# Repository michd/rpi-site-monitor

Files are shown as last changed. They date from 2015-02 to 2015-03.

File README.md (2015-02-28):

# Raspberry Pi Site monitor

A dual colour LED-based website monitor for the Raspberry Pi. 

Using red+green 3-pin LEDs, you can create 3 colours: red, green, and yellow. These work well for status indication, so they are a good choice for a website monitor.

There's a bit of python in here that deals with the Raspberry PI's General Purpose In/Out (GPIO) pins, which drives the LEDs. The rest is dealt with through a Bash script.

The bash script first pings a hostname (such as example.com). If it doesn't respond to ping, it will turn the LED to red. If it does respond to ping, it will use curl to determine the HTTP status of a given page on the website. If this status is 200 or 204, it will turn the LED to green. If the HTTP status is anything else, yellow.

If you're better at reading pseudo code instead of text:

```
if (site responds to ping):
  if (page http status is 200 or 204):
    LED color = green
  else:
    LED color = yellow
else:
  LED color = red
```

## Requirements

- Hardware:
  - A Raspberry pi set up with networking
  - Some red+green dual color LEDs (or just a red and green LED per site)
  - NPN transistors to drive the LEDs (BC547-B will do fine)
  - Some resistors (I used 2x 1k Ohm + 2x 220 Ohm per dual colour LED)
  
  Refer to the eagle folder for a schematic and a PCB design with 5 LEDs set up.
- Software:
  - Python
  - Python RPi.GPIO
  - Curl

## Usage

Clone or download the repository, wire up the electronics. In a terminal on your RPi, go to the directory with this code, and run:

```
sudo ./monitor
```

If that doesn't work (probably if you've downloaded this a zip), make `monitor` executable:

```
chmod +x monitor
```

and try running it again. It won't produce any output, and will keep running until you hit Ctrl-C.

### Customise your configuration

By defauly, site monitor uses, you guessed it, default.conf for the configuration. This file contains documented settings and three example websites to status check. To use it for your own sites, make a copy of `default.conf`, and edit it with your favorite text editor. Then, run monitor, specifying your new config as an argument:

```
sudo ./monitor my-config.conf
```

### Console output
To see the status is of the things you're testing, run it with `-v` or `-vv` for more detail:

```
sudo ./monitor -v
```

## To do

See [Issues](https://github.com/michd/rpi-site-monitor/issues) on GitHub.

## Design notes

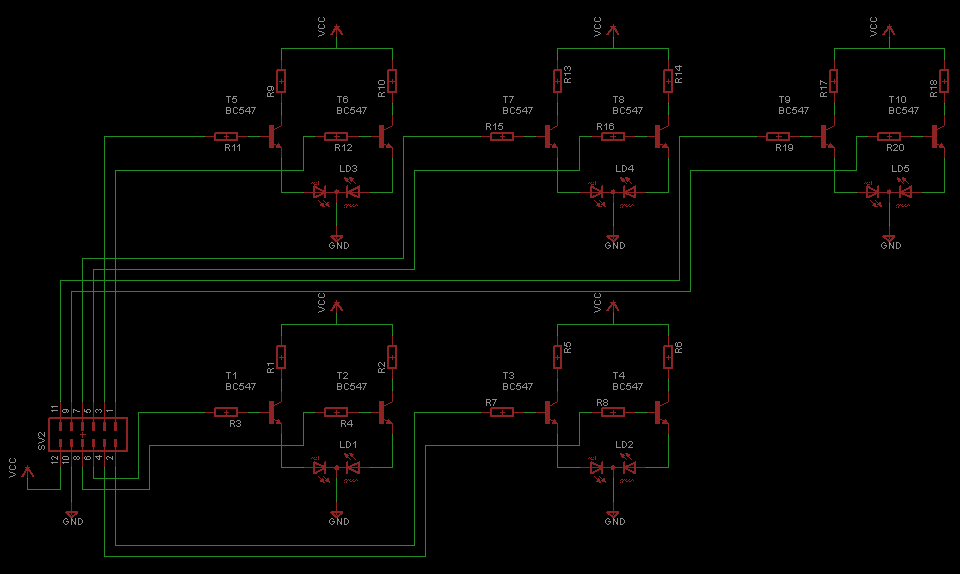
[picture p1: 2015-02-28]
eagle/5-leds-schematic.PNG

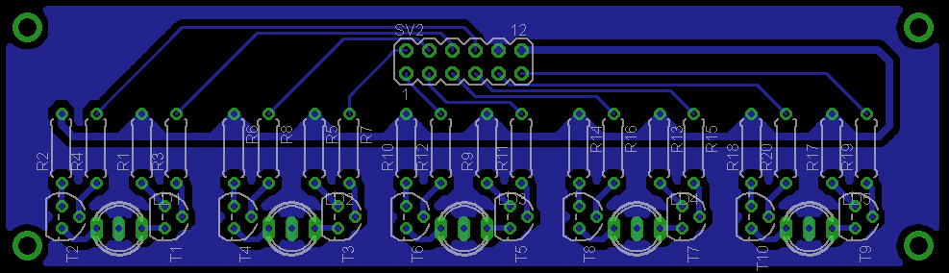
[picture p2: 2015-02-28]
eagle/5-leds-board.png

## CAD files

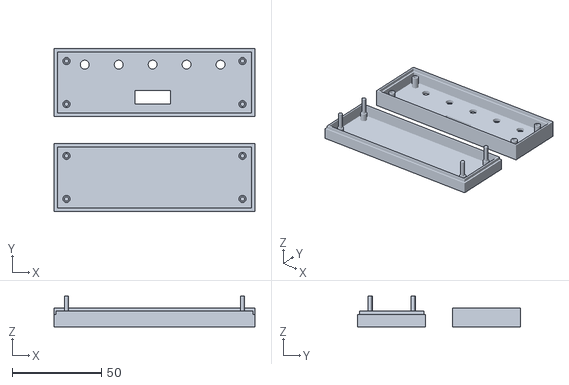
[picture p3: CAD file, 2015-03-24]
openscad/box.stl
112.5 x 91.2 x 17.3

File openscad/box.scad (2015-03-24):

// This design is parameterized based on holes in a PCB.
// It assumes that the PCB has 4 holes, evenly spaced as
// corners of a rectangle.

// Note: width refers to X axis, depth to Y, height to Z

// Edit these parameters for your own board dimensions

ceiling_distance_to_board = 7;

wall_thickness = 2;
floor_thickness = 2;
ceiling_thickness = 2;


hole_spacing_x = 98.5;
hole_spacing_y = 24.1;

hole_diameter = 2.5;
standoff_diameter = 4;

// How much the PCB needs to be raised from the bottom
// to leave room for solderings and whatnot
standoff_height = 5;
board_thickness = 1.65;


bottom_wall_height = standoff_height;
top_wall_height = ceiling_distance_to_board + board_thickness;
// Total height of box = floor_thickness + ceiling_thickness + bottom_wall_height + top_wall_height

// padding between standoff and wall
padding_left = 3;
padding_right = 3;
padding_back = 3;
padding_front = 3;

// ridge where bottom and top off box can overlap
// Make sure this isn't less than top_wall_height
ridge_height = 2;

// Project-specific params
led_diameter = 5;
first_led_offset_x = 10.2;
first_led_offset_y = 2;
led_origin_spacing = 19;
num_leds = 5;

connector_origin_x = 48.3;
connector_origin_y = 20.3;
connector_width = 20;
connector_depth = 7.5;

//-------------------------------------------------------------------

// Calculated globals
pin_height = bottom_wall_height + top_wall_height - standoff_height; 


module ceilingless_box(width, depth, height) {
    // Floor
    cube([width, depth, floor_thickness]);
    
    // Left wall
    translate([0, 0, floor_thickness])
        cube([
            wall_thickness,
            depth,
            height]);
    
    // Right wall
    translate([width - wall_thickness, 0, floor_thickness])
        cube([
            wall_thickness,
            depth,
            height]);
    
    // Rear wall
    translate([wall_thickness, depth - wall_thickness, floor_thickness])
        cube([
            width - 2 * wall_thickness,
            wall_thickness,
            height]);
    
    // Front wall
    translate([wall_thickness, 0, floor_thickness])
        cube([
            width - 2 * wall_thickness,
            wall_thickness,
            height]);
}

module bottom_case() {
    floor_width = hole_spacing_x + standoff_diameter + padding_left + padding_right + wall_thickness * 2;
    floor_depth = hole_spacing_y + standoff_diameter + padding_front + padding_back + wall_thickness * 2;
    
    module box() {
        ceilingless_box(floor_width, floor_depth, bottom_wall_height);        
        
        // Left Ridge
        translate([
            wall_thickness / 2,
            wall_thickness / 2,
            floor_thickness + bottom_wall_height])
            cube([
                wall_thickness / 2,
                floor_depth - wall_thickness,
                ridge_height]);
        
        
        // Right Ridge
        translate([
            floor_width - wall_thickness,
            wall_thickness / 2,
            floor_thickness + bottom_wall_height])
            cube([
                wall_thickness / 2,
                floor_depth - wall_thickness,
                ridge_height]);
                
        // Rear Ridge
        translate([
            wall_thickness,
            floor_depth - wall_thickness,
            floor_thickness + bottom_wall_height])
            cube([
                floor_width - wall_thickness * 2,
                wall_thickness / 2,
                ridge_height]);
                
        // Front Ridge
        translate([
            wall_thickness,
            wall_thickness / 2,
            floor_thickness + bottom_wall_height])
            cube([
                floor_width - 2 * wall_thickness,
                wall_thickness / 2,
                ridge_height
            ]);
    }
        
    
    // Place the standoffs and through-PCB pins in the box
    module pcb_holder() {        
        base_offset_x = wall_thickness + padding_left + standoff_diameter / 2;
        base_offset_y = wall_thickness + padding_front + standoff_diameter / 2;
        
        module pin() {
            // Standoff
            translate([0, 0,  standoff_height / 2])
                cylinder(
                    r = standoff_diameter / 2,
                    h = standoff_height,
                    center = true,
                    $fn = 20);
            
            // Through-PCB ping
            translate([0, 0, standoff_height + (board_thickness + pin_height) / 2])
                cylinder(
                    r = hole_diameter / 2,
                    h = board_thickness + pin_height,
                    center = true,
                    $fn = 20);
        }
        
        // Front left
        translate([base_offset_x, base_offset_y, floor_thickness])
            pin();
        
        // Front right
        translate([base_offset_x + hole_spacing_x, base_offset_y, floor_thickness])
            pin();
        
        // Rear left
        translate([base_offset_x, base_offset_y + hole_spacing_y, floor_thickness])
            pin();
        
        // Rear right
        translate([base_offset_x + hole_spacing_x, base_offset_y + hole_spacing_y, floor_thickness])
            pin();
        
    }
    
    box();
    pcb_holder();
}
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

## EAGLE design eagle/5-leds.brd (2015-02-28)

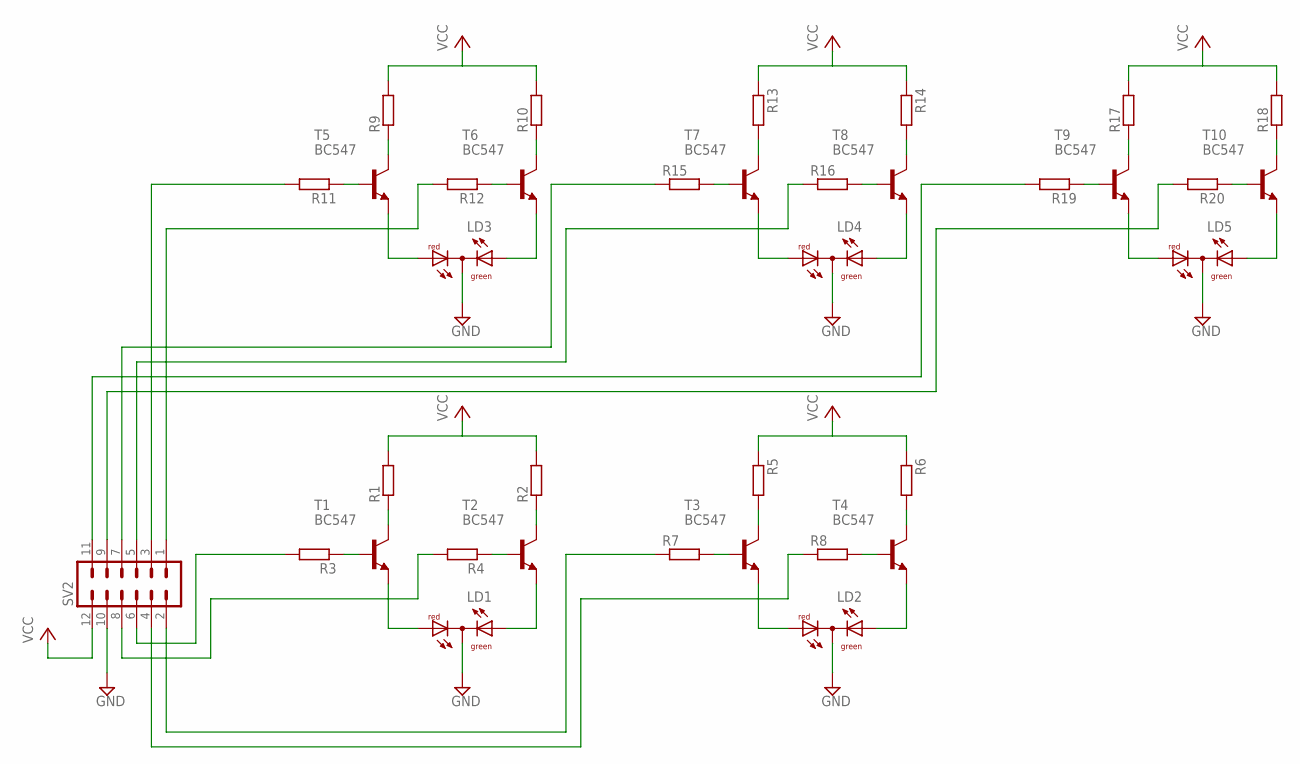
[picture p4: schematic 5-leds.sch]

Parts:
LD1, LD2, LD3, LD4, LD5: DUOLED-RG-C; DUOLED-C-5MM
R1, R2, R3, R4, R5, R6, R7, R8, R9, R10, R11, R12, R13, R14, R15, R16, R17, R18, R19, R20: R-EU_0207/7; 0207/7
SV2: MA06-2
T1, T2, T3, T4, T5, T6, T7, T8, T9, T10: BC547; TO92

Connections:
GND: LD1.C, LD2.C, LD3.C, LD4.C, LD5.C, SV2.10
unnamed: LD1.AR, T1.1 (E)
unnamed: LD1.AX (AG), T2.1 (E)
unnamed: R3.1, T1.2 (B)
unnamed: R4.1, T2.2 (B)
unnamed: R4.2, SV2.8
unnamed: R3.2, SV2.6
unnamed: R1.1, T1.3 (C)
unnamed: R2.1, T2.3 (C)
unnamed: LD2.AR, T3.1 (E)
unnamed: LD2.AX (AG), T4.1 (E)
unnamed: R8.1, SV2.4
unnamed: R5.2, T3.3 (C)
unnamed: R6.2, T4.3 (C)
unnamed: R7.2, T3.2 (B)
unnamed: R8.2, T4.2 (B)
unnamed: R7.1, SV2.2
unnamed: LD3.AR, T5.1 (E)
unnamed: LD3.AX (AG), T6.1 (E)
unnamed: R12.2, SV2.1
unnamed: R9.1, T5.3 (C)
unnamed: R10.1, T6.3 (C)
unnamed: R11.1, T5.2 (B)
unnamed: R12.1, T6.2 (B)
unnamed: R11.2, SV2.3
unnamed: LD4.AR, T7.1 (E)
unnamed: LD4.AX (AG), T8.1 (E)
unnamed: R16.1, SV2.5
unnamed: R13.2, T7.3 (C)
unnamed: R14.2, T8.3 (C)
unnamed: R15.2, T7.2 (B)
unnamed: R16.2, T8.2 (B)
unnamed: R15.1, SV2.7
unnamed: LD5.AR, T9.1 (E)
unnamed: LD5.AX (AG), T10.1 (E)
unnamed: R20.2, SV2.9
unnamed: R17.1, T9.3 (C)
unnamed: R18.1, T10.3 (C)
unnamed: R19.1, T9.2 (B)
unnamed: R20.1, T10.2 (B)
unnamed: R19.2, SV2.11
VCC: R1.2, R2.2, R5.1, R6.1, R9.2, R10.2, R13.1, R14.1, R17.2, R18.2, SV2.12

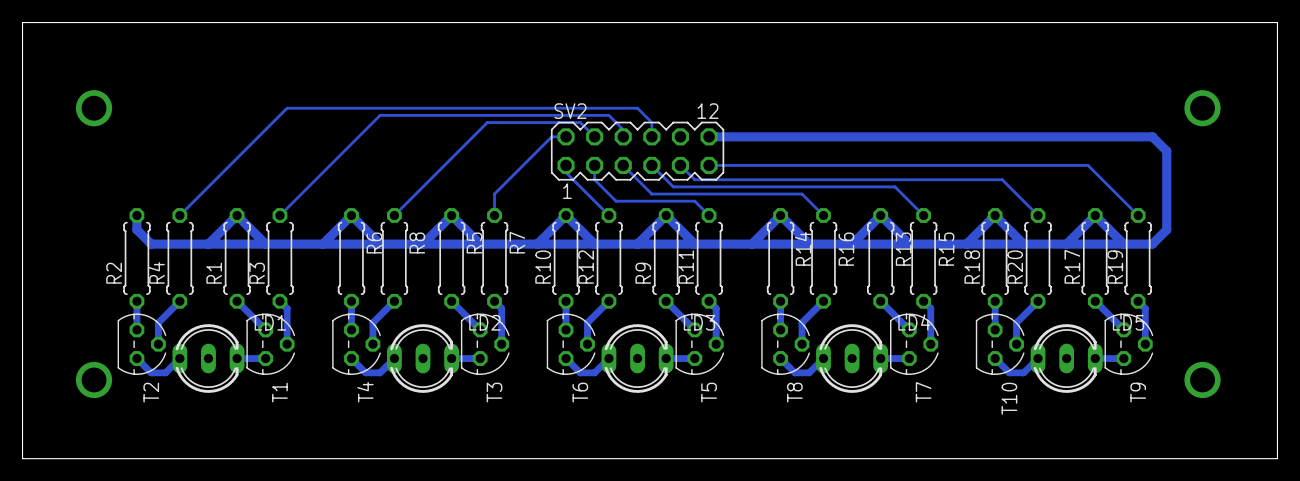
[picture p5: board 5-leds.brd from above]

Board: 2 copper layers, 111.4 x 38.7 mm, 36 parts (0 on the bottom side), 42 nets.

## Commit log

2015-02-27 Add eagle circuit for board with 5 LEDs
    [5-leds.sch]
2015-02-28 Tweak schematic, design board
    [5-leds.brd, 5-leds.sch]
2015-02-28 Use config files for site / LED pin setup. Closes #1
2015-03-23 Started working on a box for it in openscad, only have bottom half so far
    [box.scad, box.stl]
2015-03-24 Finished generic box, just needs holes for LEDs and connector
    [box.scad, box.stl]
2015-03-24 Finish box design
    [box.scad, box.stl]
